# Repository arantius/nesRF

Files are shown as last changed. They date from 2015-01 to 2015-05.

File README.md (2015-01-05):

nesRF is a project to retrofit wireless capability into otherwise standard
NES and SNES video game controllers.  It is both hardware (schematic and PCB)
and software (running on an ATMega microcontroller).

The primary goals are:

* Clean design.  External appearance should be minimal, with few visible
  changes from the original stock hardware, besides removing the wire.
* Cross-compatibility: especially, the SNES controller will co-operate with
  either the SNES or NES receiver.

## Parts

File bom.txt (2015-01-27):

TX:

All 0402 capacitors and resistors:

C 0.1u * 4
C 4.7u * 2
C 1u

R 10k * 4
R 19.1k
R 180
R 300k
R 100k

One each:

MCU: ATMEGA328A TQPF-32
Voltage regulator: TCR2EF25,LM(CT SOT-23-5
Li-ion charger: MCP73832T-2ACI/OT SOT-23-5
Voltage detector: BD49K30G-TL SSOP-3
TVS: VC060305A150DP 0603
ISP Header: M20-9980345
Illuminated pushbutton: WBL2UEEGYQR05CLR

RX:

All 0402 capacitors and resistors:

C 0.1u * 4
C 1u

R 10k * 2
R 180

One each:

MCU: ATMEGA328A TQPF-32
Bi-color LED: WP59GYW
ISP Header: M20-9980345

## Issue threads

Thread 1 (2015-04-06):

SNES TX PCB Shape

arantius, 2015-04-06:
A couple issues with the shape of this PCB:

1. Major: there's no space for the pivot points of the shoulder buttons.  This can, barely, be dremeled out safely without affecting performance.
2. The cutout for the R shoulder button daughter board is almost perfect, but a very tight fit.  The L on the other hand is too loose in every dimension.  Somewhere in between the two would be best.

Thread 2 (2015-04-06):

SNES RX Should be interrupt driven

arantius, 2015-04-06:
I was too obsessed with parts count reduction.  I included no crystals anywhere, relying on the 8MHz RC circuit.  Early tests showed this to be sufficient.  To make this work, I had to go mostly software driven, as I couldn't reliably interrupt in 6ms based on the clock signal, when building the SNES RX.

Turns out I also can't reliably interrupt with the 18ms available completely 100% of the time from latch rise to first clock drop, either.  Occasionally as a result buttons get missed.  Now that I've done the NES RX, fully interrupt driven -- and at 16MHz because I expected it to be more difficult to handle both players -- I'm pretty confident that it would be better to fully interrupt drive the SNES RX as well.  But again, at 8MHz that doesn't seem possible.

arantius, 2015-05-25:
f2887791ccca9e47665a93060e8486ed92c85b78 c5f8425099a87a260d53bb1839957d2f6069903e

Closed 2015-05-25.

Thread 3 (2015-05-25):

NES transmitter range

arantius, 2015-05-25:
Unfortunately the RF board ended up sandwiched between the original PCB and my add-in daughterboard.  It seems that this has some consequences to the effective range, with the antenna surrounded by quite a lot of material.

I think redesigning so the RF board is at the absolute bottom of the stack should help, as (at least personally) the controller tends to be held around a 45 degree angle, with the bottom well exposed towards the console.  This may have the side benefit of locating the power jack closer to the original hole for the wire, but would probably involve a complete redesign of the board.

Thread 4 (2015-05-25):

NES transmitter shape

arantius, 2015-05-25:
The cutout around the screw support isn't lined up well, a shaving a bit of that support off is necessary.

The switch is not located well, shaving off a bit of the inside of the case is necessary to make it fit.  It should come in by up to ~1mm.

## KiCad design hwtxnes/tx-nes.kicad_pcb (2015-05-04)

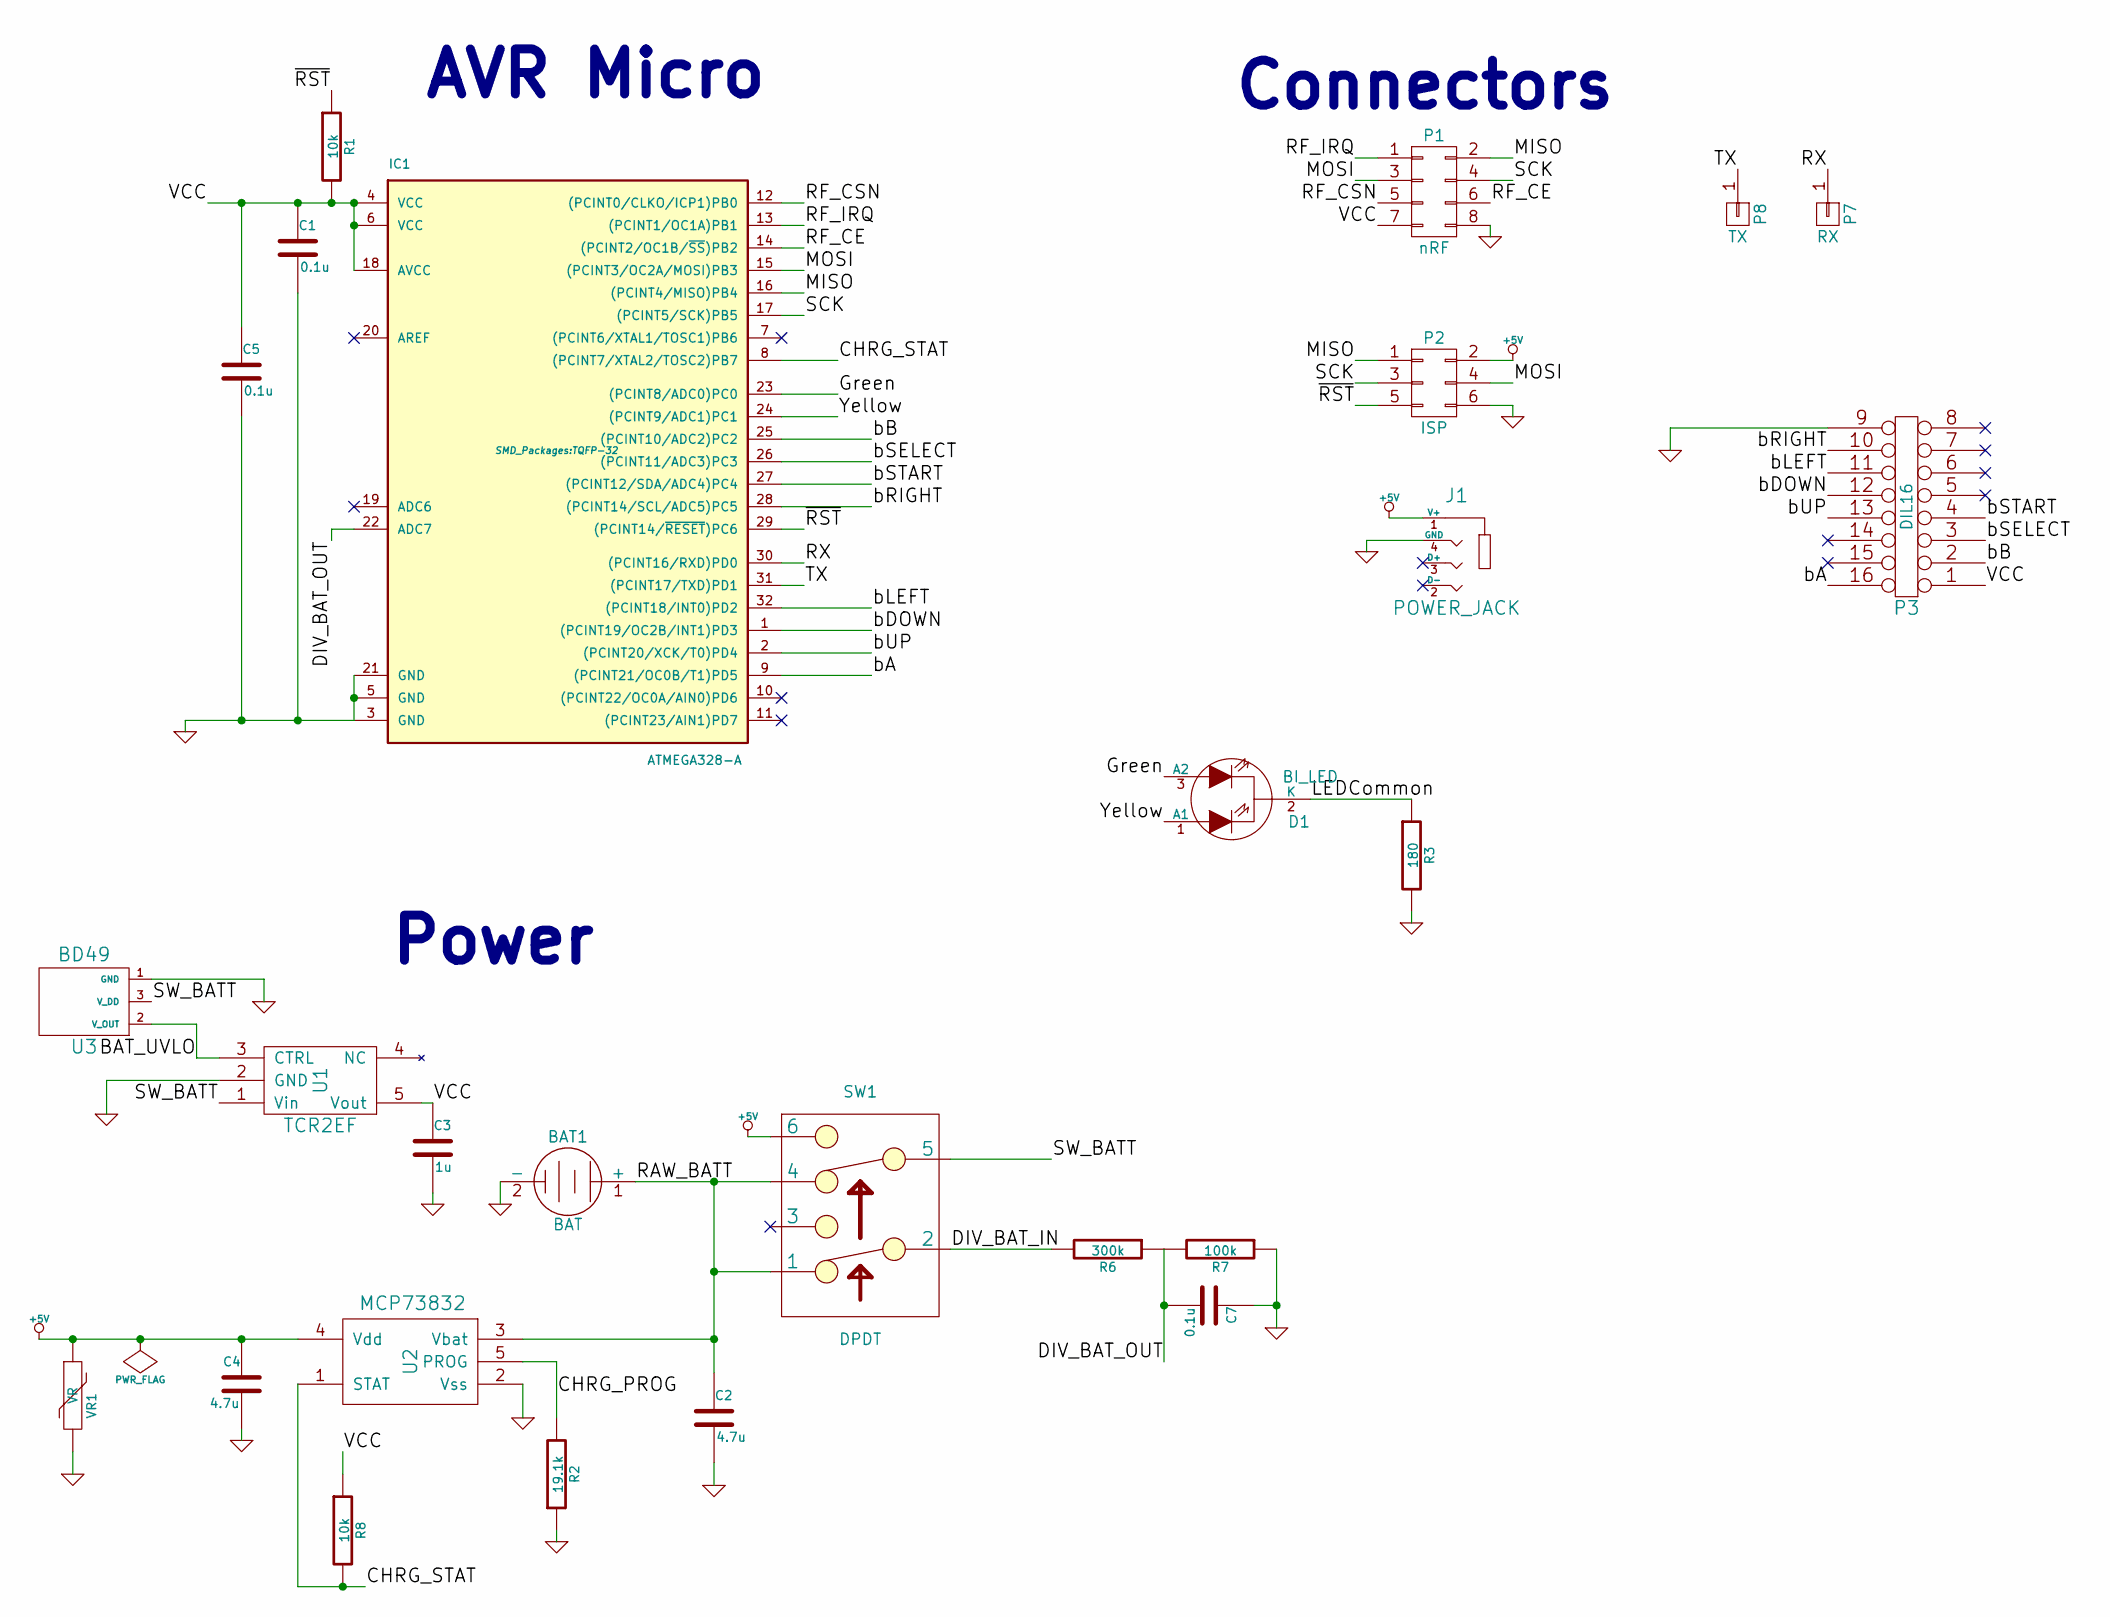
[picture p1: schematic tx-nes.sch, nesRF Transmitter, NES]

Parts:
BAT1: BAT; PINHEAD1-2
C1, C5, C7: 0.1u; C_0402
C2, C4: 4.7u; C_0402
C3: 1u; C_0402
D1: BI_LED; Pin_Header_Straight_1x03
IC1: ATMEGA328-A; TQFP-32
J1: POWER_JACK; SJ-4351x
P1: nRF; nRF_Header_2x04
P2: ISP; ISP_POGO
P3: DIL16; NES_PCB_INTERCONNECT
P7: RX; SolderWirePad_single_0-8mmDrill
P8: TX; SolderWirePad_single_0-8mmDrill
R1, R8: 10k; R_0402
R2: 19.1k; R_0402
R3: 180; R_0402
R6: 300k; R_0402
R7: 100k; R_0402
SW1: DPDT; SK22D01
U1: TCR2EF; SOT23-5
U2: MCP73832; SOT23-5
U3: BD49; SSOP-3
VR1: VR; SMD-0603

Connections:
+5V: C4.1, J1.1 (V+), P2.2, SW1.6, U2.4 (Vdd), VR1.1
/BAT_UVLO: U1.3 (CTRL), U3.2 (V_OUT)
/CHRG_PROG: R2.2, U2.5 (PROG)
/CHRG_STAT: IC1.8 ((PCINT7/XTAL2/TOSC2)PB7), R8.2, U2.1 (STAT)
/DIV_BAT_IN: R6.2, SW1.2
/DIV_BAT_OUT: C7.2, IC1.22 (ADC7), R6.1, R7.2
/Green: D1.3 (A2), IC1.23 ((PCINT8/ADC0)PC0)
/LEDCommon: D1.2 (K), R3.1
/MISO: IC1.16 ((PCINT4/MISO)PB4), P1.2, P2.1
/MOSI: IC1.15 ((PCINT3/OC2A/MOSI)PB3), P1.3, P2.4
/RAW_BATT: BAT1.1 (+), C2.1, SW1.1, SW1.4, U2.3 (Vbat)
/RF_CE: IC1.14 ((PCINT2/OC1B/~SS~)PB2), P1.6
/RF_CSN: IC1.12 ((PCINT0/CLKO/ICP1)PB0), P1.5
/RF_IRQ: IC1.13 ((PCINT1/OC1A)PB1), P1.1
/RX: IC1.30 ((PCINT16/RXD)PD0), P7.1
/SCK: IC1.17 ((PCINT5/SCK)PB5), P1.4, P2.3
/SW_BATT: SW1.5, U1.1 (Vin), U3.3 (V_DD)
/TX: IC1.31 ((PCINT17/TXD)PD1), P8.1
/VCC: C1.1, C3.1, C5.1, IC1.4 (VCC), IC1.6 (VCC), IC1.18 (AVCC), P1.7, P3.1, R1.2, R8.1, U1.5 (Vout)
/Yellow: D1.1 (A1), IC1.24 ((PCINT9/ADC1)PC1)
/bA: IC1.9 ((PCINT21/OC0B/T1)PD5), P3.16
/bB: IC1.25 ((PCINT10/ADC2)PC2), P3.2
/bDOWN: IC1.1 ((PCINT19/OC2B/INT1)PD3), P3.12
/bLEFT: IC1.32 ((PCINT18/INT0)PD2), P3.11
/bRIGHT: IC1.28 ((PCINT14/SCL/ADC5)PC5), P3.10
/bSELECT: IC1.26 ((PCINT11/ADC3)PC3), P3.3
/bSTART: IC1.27 ((PCINT12/SDA/ADC4)PC4), P3.4
/bUP: IC1.2 ((PCINT20/XCK/T0)PD4), P3.13
/~RST: IC1.29 ((PCINT14/~RESET~)PC6), P2.5, R1.1
GND: BAT1.2 (-), C1.2, C2.2, C3.2, C4.2, C5.2, C7.1, IC1.3 (GND), IC1.5 (GND), IC1.21 (GND), J1.4 (GND), P1.8, P2.6, P3.9, R2.1, R3.2, R7.1, U1.2 (GND), U2.2 (Vss), U3.1 (GND), VR1.2

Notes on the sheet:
Connectors
AVR Micro
Power

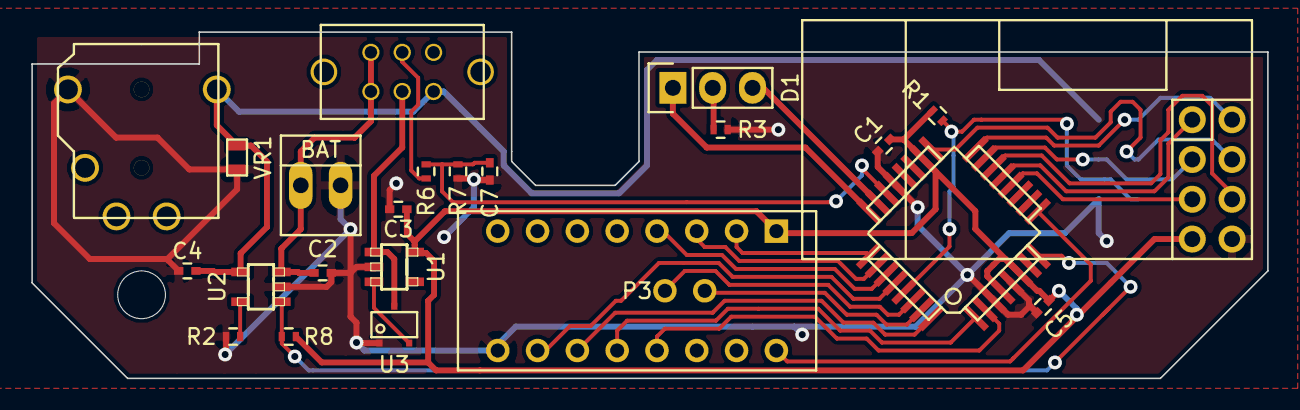
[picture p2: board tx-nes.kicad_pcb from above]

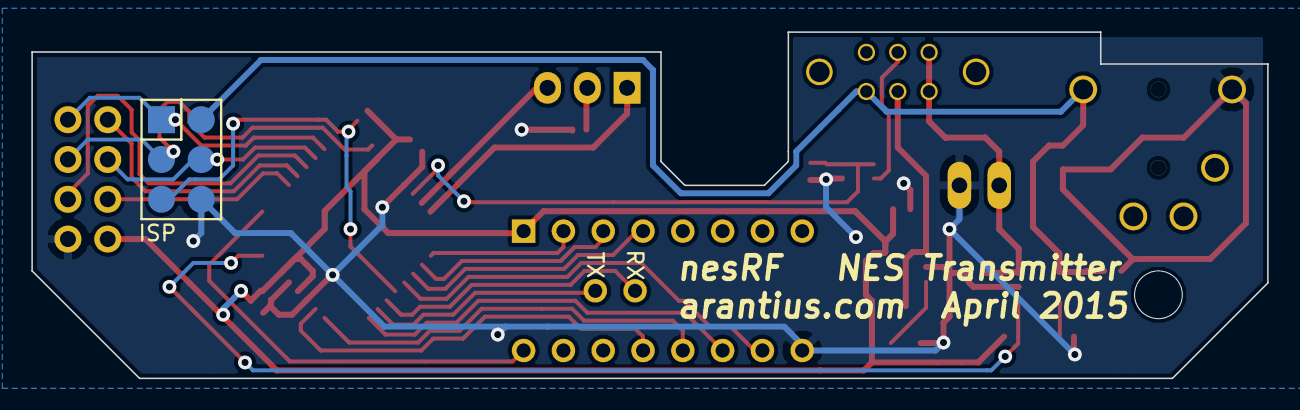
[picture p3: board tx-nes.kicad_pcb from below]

Board: 2 copper layers, 78.9 x 22.1 mm, 27 parts (3 on the bottom side), 30 nets.

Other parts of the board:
Mount_Hole: 1pin; NPTH_90

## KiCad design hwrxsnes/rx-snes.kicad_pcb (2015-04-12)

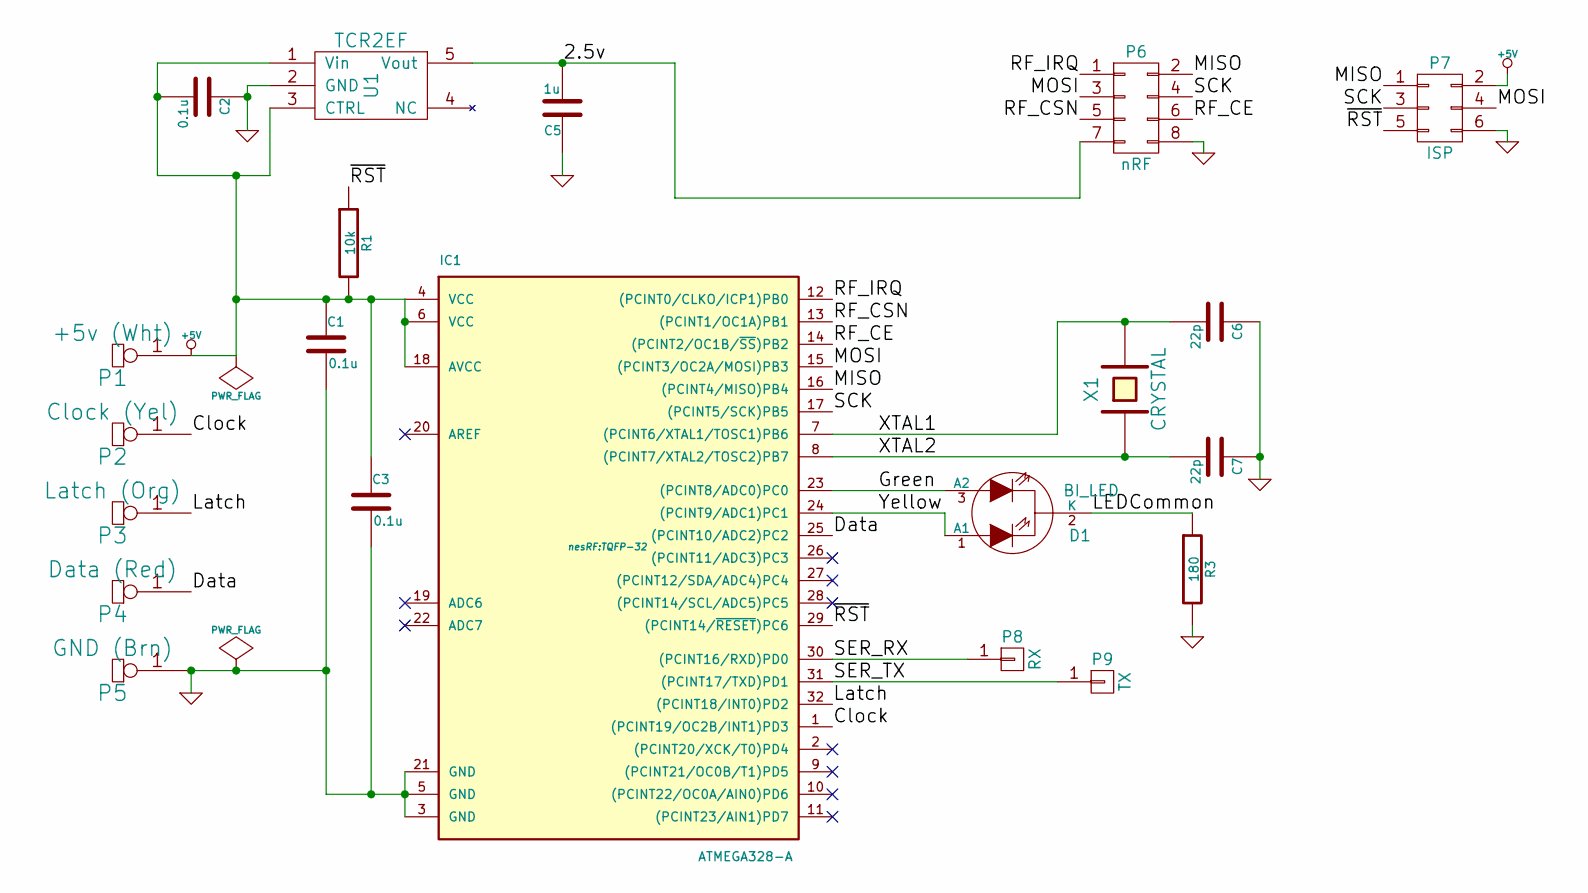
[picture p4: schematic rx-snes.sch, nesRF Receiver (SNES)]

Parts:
C1, C2, C3: 0.1u; C_0402
C5: 1u; C_0402
C6, C7: 22p; C_0402
D1: BI_LED; Pin_Header_Straight_1x03
IC1: ATMEGA328-A; TQFP-32
P1: +5v (Wht); Small_1x_Pad
P2: Clock (Yel); Small_1x_Pad
P3: Latch (Org); Small_1x_Pad
P4: Data (Red); Small_1x_Pad
P5: GND (Brn); Small_1x_Pad
P6: nRF; Pin_Header_Straight_2x04
P7: ISP; ISP_POGO
P8: RX; Small_1x_Pad
P9: TX; Small_1x_Pad
R1: 10k; R_0402
R3: 180; R_0402
U1: TCR2EF; SOT23-5
X1: CRYSTAL; TSX-3225

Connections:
+5V: C1.1, C2.2, C3.1, IC1.4 (VCC), IC1.6 (VCC), IC1.18 (AVCC), P1.1, P7.2, R1.2, U1.1 (Vin), U1.3 (CTRL)
/2.5v: C5.2, P6.7, U1.5 (Vout)
/Clock: IC1.1 ((PCINT19/OC2B/INT1)PD3), P2.1
/Data: IC1.25 ((PCINT10/ADC2)PC2), P4.1
/Green: D1.3 (A2), IC1.23 ((PCINT8/ADC0)PC0)
/LEDCommon: D1.2 (K), R3.1
/Latch: IC1.32 ((PCINT18/INT0)PD2), P3.1
/MISO: IC1.16 ((PCINT4/MISO)PB4), P6.2, P7.1
/MOSI: IC1.15 ((PCINT3/OC2A/MOSI)PB3), P6.3, P7.4
/RF_CE: IC1.14 ((PCINT2/OC1B/~SS~)PB2), P6.6
/RF_CSN: IC1.13 ((PCINT1/OC1A)PB1), P6.5
/RF_IRQ: IC1.12 ((PCINT0/CLKO/ICP1)PB0), P6.1
/SCK: IC1.17 ((PCINT5/SCK)PB5), P6.4, P7.3
/SER_RX: IC1.30 ((PCINT16/RXD)PD0), P8.1
/SER_TX: IC1.31 ((PCINT17/TXD)PD1), P9.1
/XTAL1: C6.2, IC1.7 ((PCINT6/XTAL1/TOSC1)PB6), X1.2
/XTAL2: C7.2, IC1.8 ((PCINT7/XTAL2/TOSC2)PB7), X1.1
/Yellow: D1.1 (A1), IC1.24 ((PCINT9/ADC1)PC1)
/~RST: IC1.29 ((PCINT14/~RESET~)PC6), P7.5, R1.1
GND: C1.2, C2.1, C3.2, C5.1, C6.1, C7.1, IC1.3 (GND), IC1.5 (GND), IC1.21 (GND), P5.1, P6.8, P7.6, R3.2, U1.2 (GND)

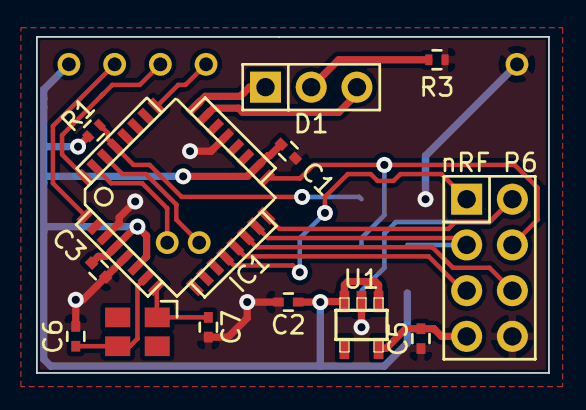
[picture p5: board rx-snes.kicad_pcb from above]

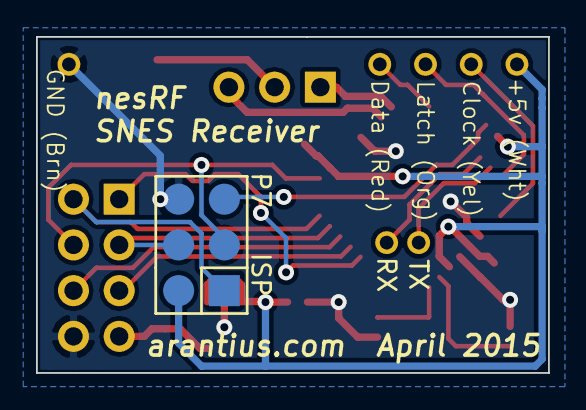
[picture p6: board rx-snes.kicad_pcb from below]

Board: 2 copper layers, 28.4 x 18.7 mm, 21 parts (3 on the bottom side), 20 nets.

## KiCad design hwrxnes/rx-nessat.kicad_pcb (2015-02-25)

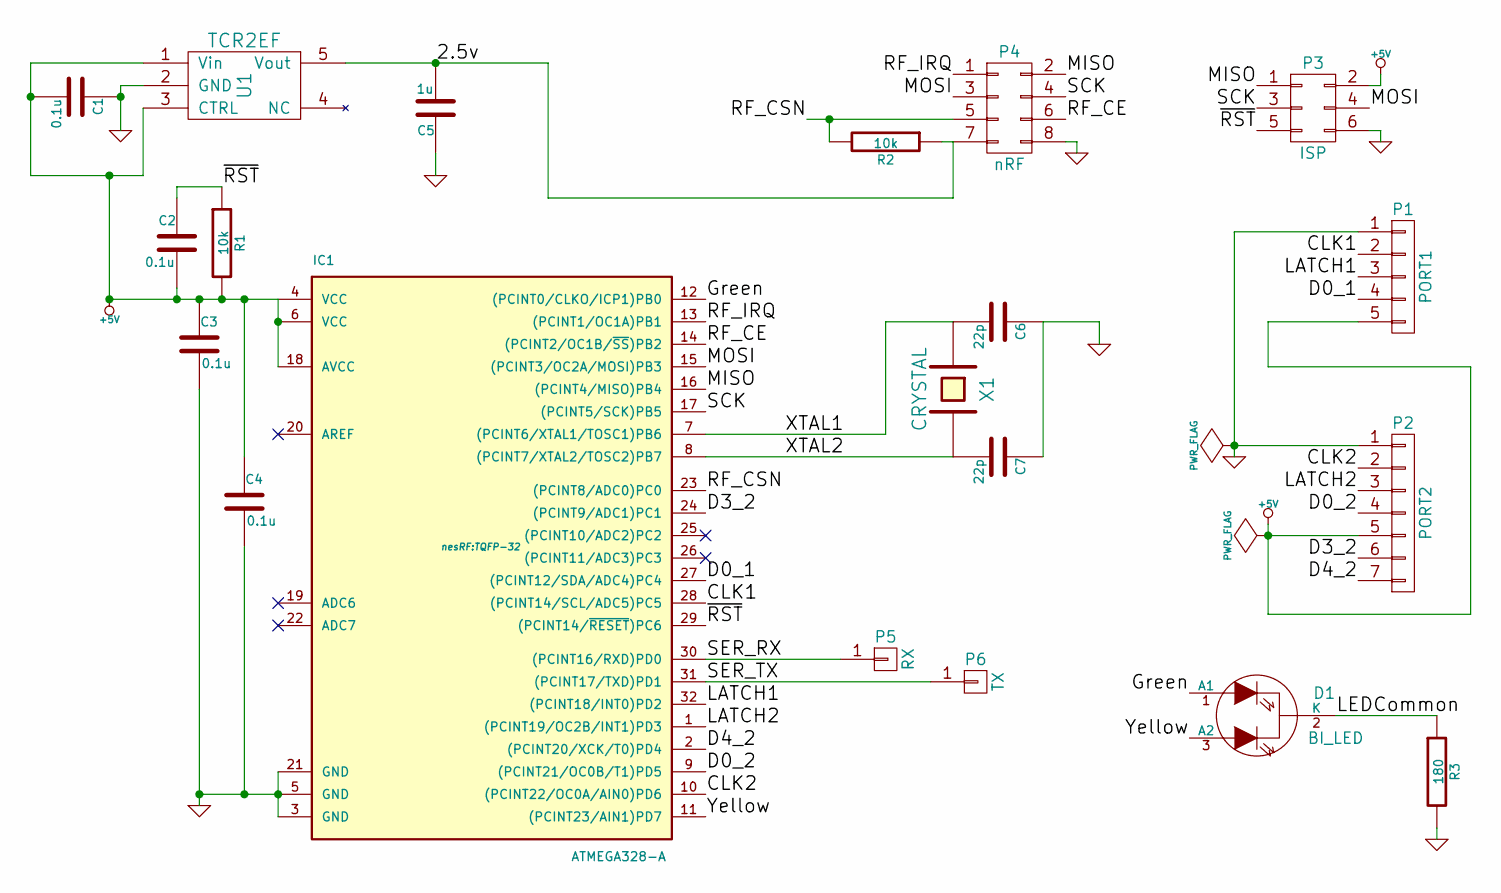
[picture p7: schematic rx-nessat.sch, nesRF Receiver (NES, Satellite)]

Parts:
C1, C2, C3, C4: 0.1u; C_0402
C5: 1u; C_0402
C6, C7: 22p; C_0402
D1: BI_LED; Pin_Header_Straight_1x03
IC1: ATMEGA328-A; TQFP-32
P1: PORT1; Pin_Header_Straight_1x05
P2: PORT2; Pin_Header_Straight_1x07
P3: ISP; Pin_Header_Straight_2x03
P4: nRF; nRF_Header_2x04
P5: RX; Small_1x_Pad
P6: TX; Small_1x_Pad
R1, R2: 10k; R_0402
R3: 180; R_0402
U1: TCR2EF; SOT23-5
X1: CRYSTAL; TSX-3225

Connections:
+5V: C1.2, C2.2, C3.1, C4.1, IC1.4 (VCC), IC1.6 (VCC), IC1.18 (AVCC), P1.5, P2.5, P3.2, R1.2, U1.1 (Vin), U1.3 (CTRL)
/2.5v: C5.2, P4.7, R2.1, U1.5 (Vout)
/CLK1: IC1.28 ((PCINT14/SCL/ADC5)PC5), P1.2
/CLK2: IC1.10 ((PCINT22/OC0A/AIN0)PD6), P2.2
/D0_1: IC1.27 ((PCINT12/SDA/ADC4)PC4), P1.4
/D0_2: IC1.9 ((PCINT21/OC0B/T1)PD5), P2.4
/D3_2: IC1.24 ((PCINT9/ADC1)PC1), P2.6
/D4_2: IC1.2 ((PCINT20/XCK/T0)PD4), P2.7
/Green: D1.1 (A1), IC1.12 ((PCINT0/CLKO/ICP1)PB0)
/LATCH1: IC1.32 ((PCINT18/INT0)PD2), P1.3
/LATCH2: IC1.1 ((PCINT19/OC2B/INT1)PD3), P2.3
/LEDCommon: D1.2 (K), R3.1
/MISO: IC1.16 ((PCINT4/MISO)PB4), P3.1, P4.2
/MOSI: IC1.15 ((PCINT3/OC2A/MOSI)PB3), P3.4, P4.3
/RF_CE: IC1.14 ((PCINT2/OC1B/~SS~)PB2), P4.6
/RF_CSN: IC1.23 ((PCINT8/ADC0)PC0), P4.5, R2.2
/RF_IRQ: IC1.13 ((PCINT1/OC1A)PB1), P4.1
/SCK: IC1.17 ((PCINT5/SCK)PB5), P3.3, P4.4
/SER_RX: IC1.30 ((PCINT16/RXD)PD0), P5.1
/SER_TX: IC1.31 ((PCINT17/TXD)PD1), P6.1
/XTAL1: C6.2, IC1.7 ((PCINT6/XTAL1/TOSC1)PB6), X1.1
/XTAL2: C7.2, IC1.8 ((PCINT7/XTAL2/TOSC2)PB7), X1.2
/Yellow: D1.3 (A2), IC1.11 ((PCINT23/AIN1)PD7)
/~RST: C2.1, IC1.29 ((PCINT14/~RESET~)PC6), P3.5, R1.1
GND: C1.1, C3.2, C4.2, C5.1, C6.1, C7.1, IC1.3 (GND), IC1.5 (GND), IC1.21 (GND), P1.1, P2.1, P3.6, P4.8, R3.2, U1.2 (GND)

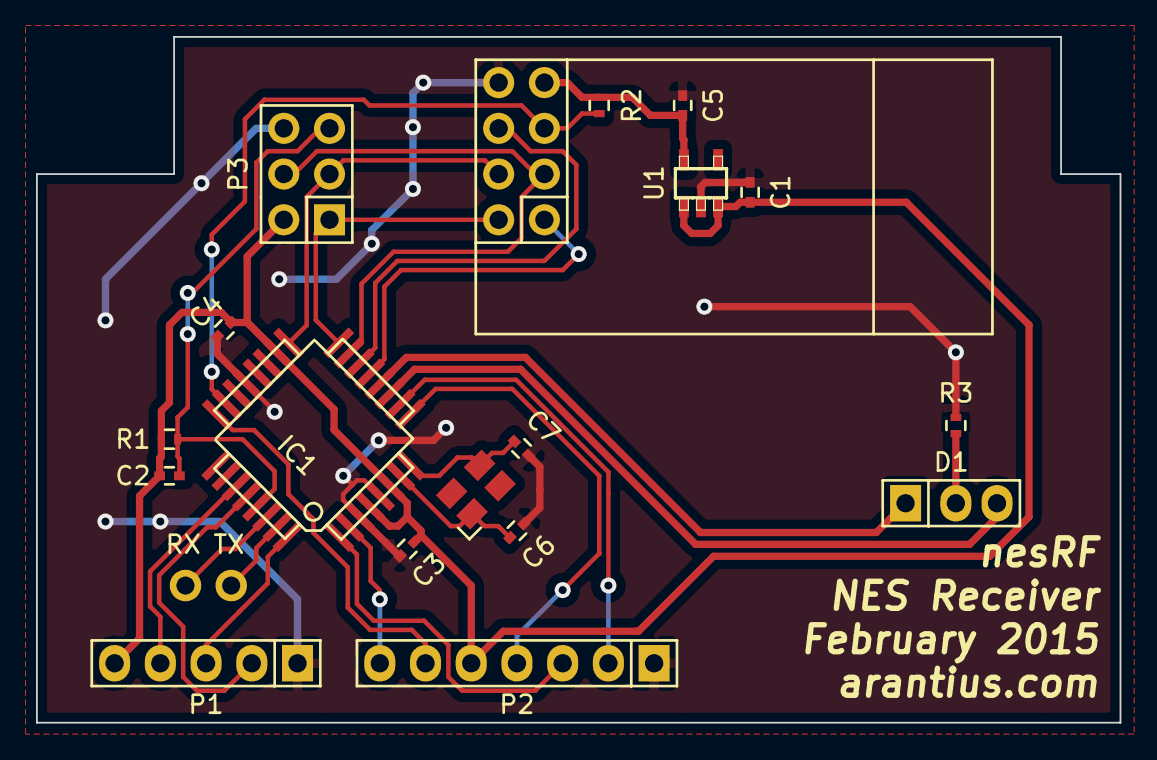
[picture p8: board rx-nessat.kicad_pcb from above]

Board: 2 copper layers, 60.2 x 38.1 mm, 20 parts (0 on the bottom side), 25 nets.

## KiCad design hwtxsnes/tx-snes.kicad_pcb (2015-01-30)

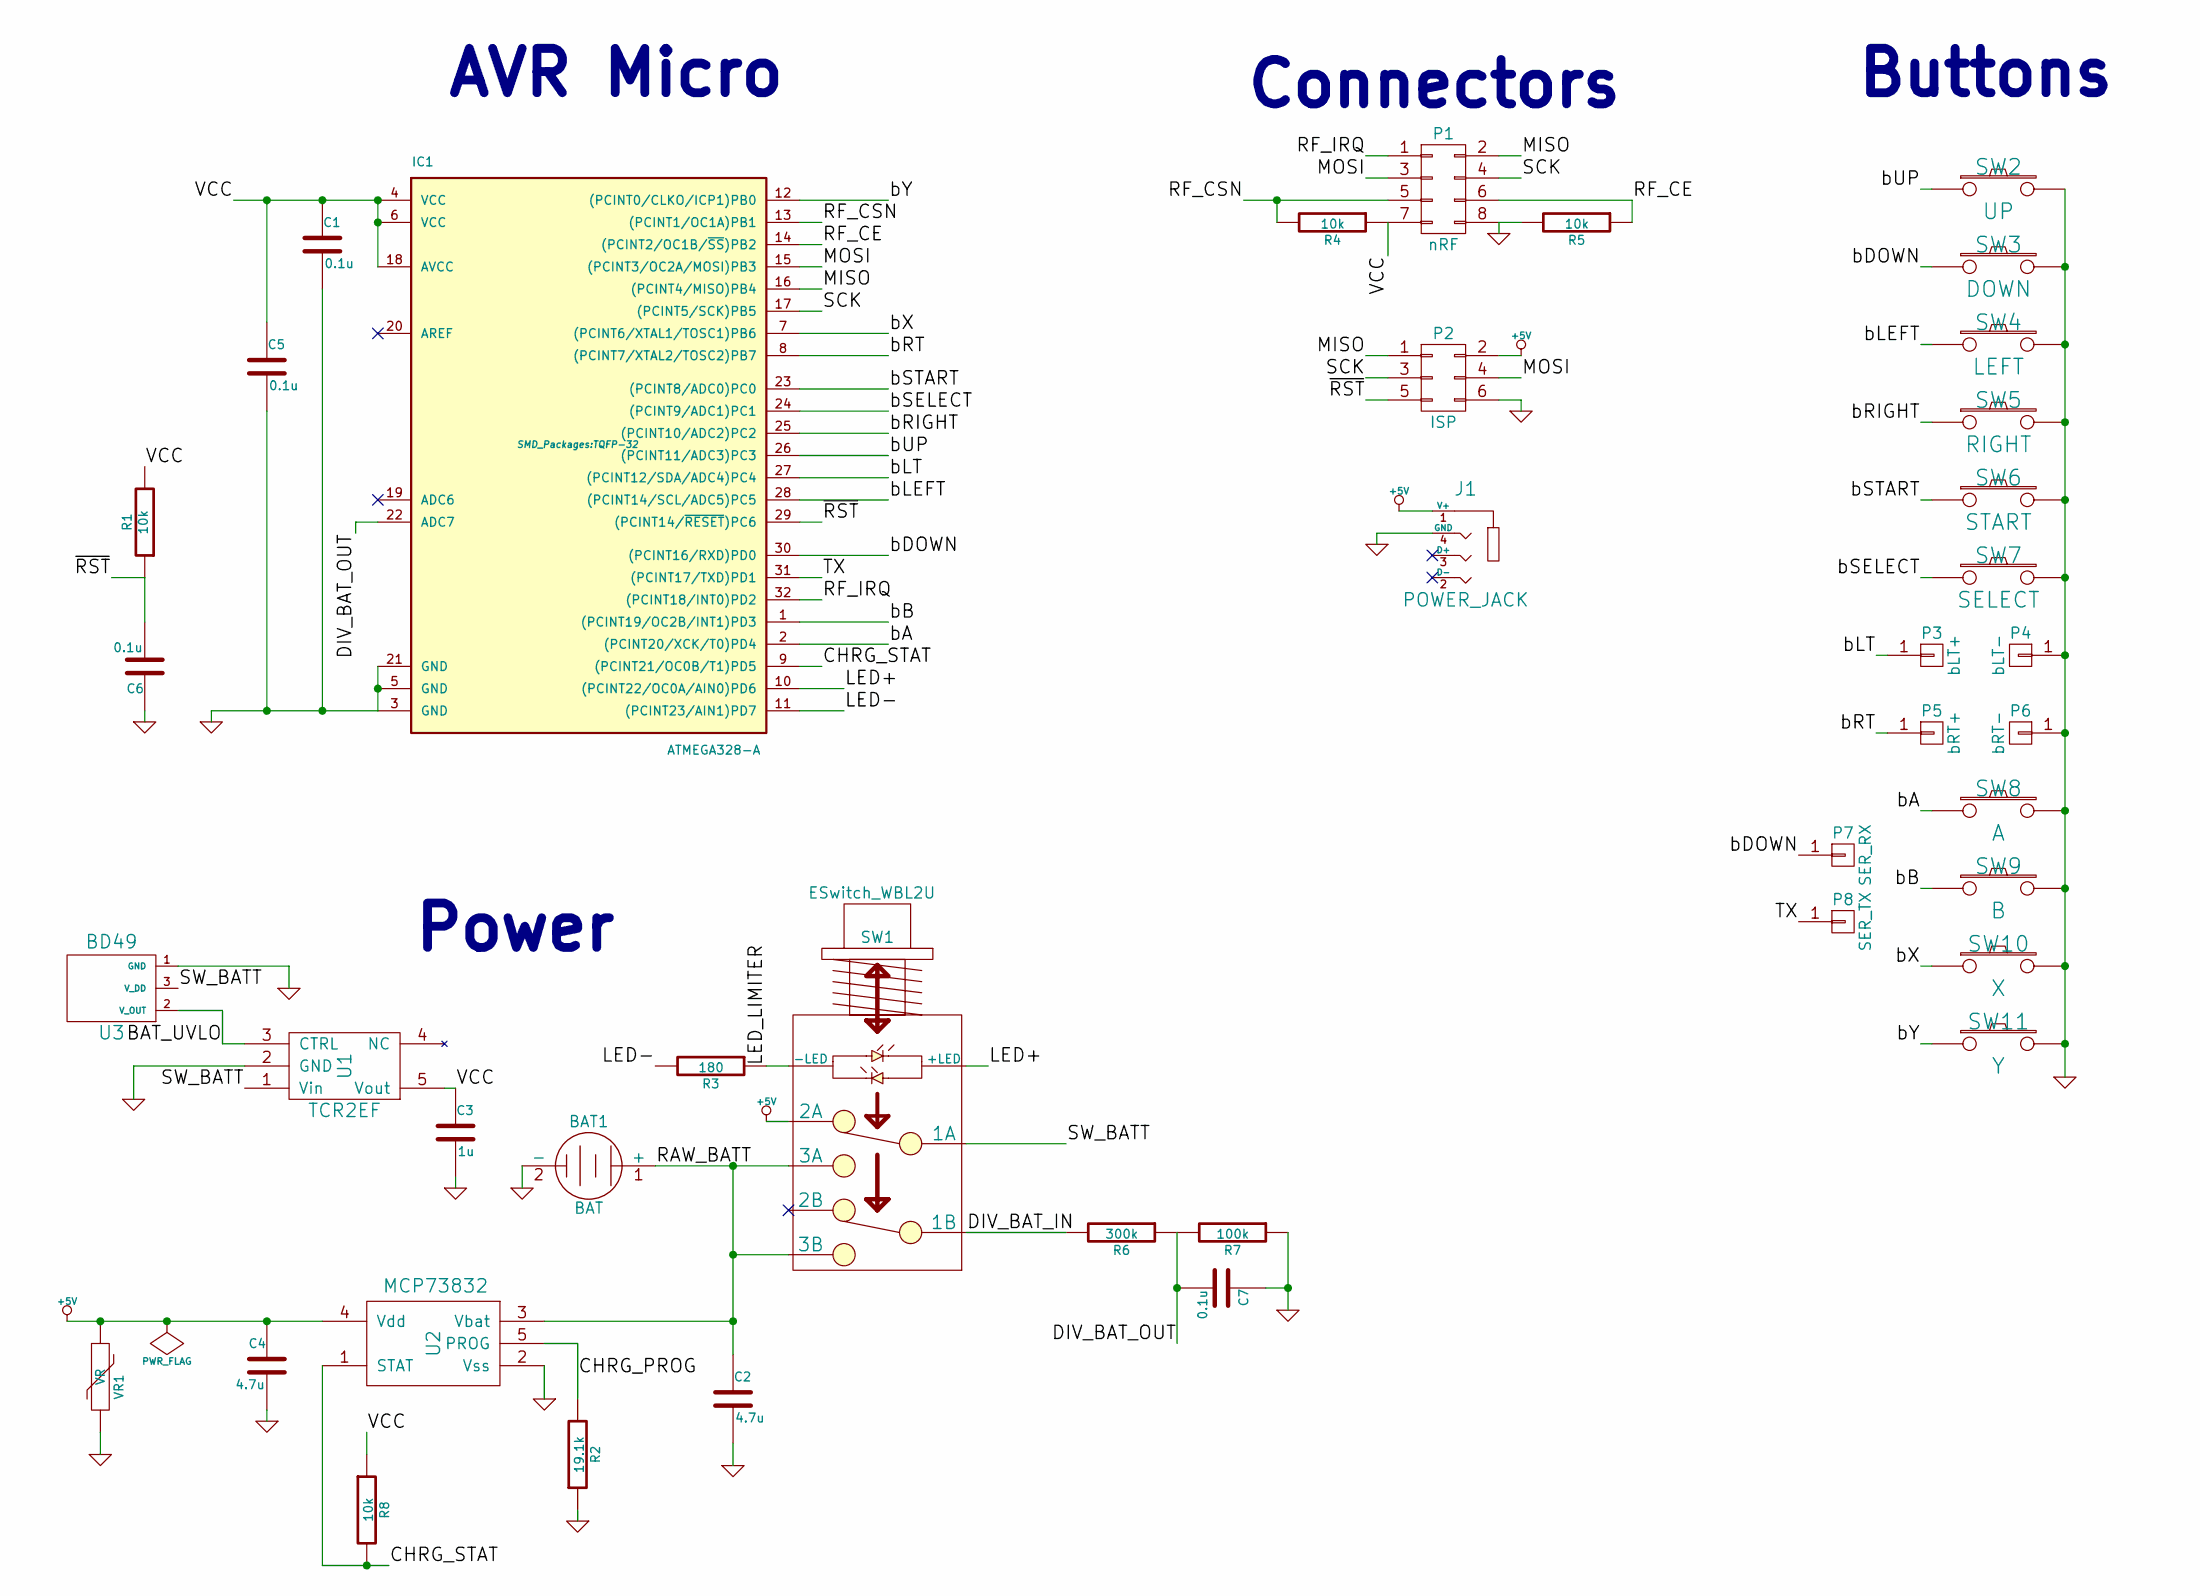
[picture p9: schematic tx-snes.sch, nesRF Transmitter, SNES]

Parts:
BAT1: BAT; PINHEAD1-2
C1, C5, C6, C7: 0.1u; SMD-0402_c
C2, C4: 4.7u; SMD-0402_c
C3: 1u; SMD-0402_c
IC1: ATMEGA328-A; TQFP-32
J1: POWER_JACK; SJ-4351x
P1: nRF; nRF_Header_2x04
P2: ISP; Pin_Header_Straight_2x03
P3: bLT+; SolderWirePad_single_0-8mmDrill
P4: bLT-; SolderWirePad_single_0-8mmDrill
P5: bRT+; SolderWirePad_single_0-8mmDrill
P6: bRT-; SolderWirePad_single_0-8mmDrill
P7: SER_RX; SolderWirePad_single_0-8mmDrill
P8: SER_TX; SolderWirePad_single_0-8mmDrill
R1, R4, R5, R8: 10k; SMD-0402_r
R2: 19.1k; SMD-0402_r
R3: 180; SMD-0402_r
R6: 300k; SMD-0402_r
R7: 100k; SMD-0402_r
SW1: ESwitch_WBL2U; Eswitch_WBL_2U
SW2: UP; Carbon_Switch_PCB_Pad
SW3: DOWN; Carbon_Switch_PCB_Pad
SW4: LEFT; Carbon_Switch_PCB_Pad
SW5: RIGHT; Carbon_Switch_PCB_Pad
SW6: START; Carbon_Switch_PCB_Pad
SW7: SELECT; Carbon_Switch_PCB_Pad
SW8: A; Carbon_Switch_PCB_Pad
SW9: B; Carbon_Switch_PCB_Pad
SW10: X; Carbon_Switch_PCB_Pad
SW11: Y; Carbon_Switch_PCB_Pad
U1: TCR2EF; SOT-23-5
U2: MCP73832; SOT-23-5
U3: BD49; SSOP-3
VR1: VR; SMD-0603

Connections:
+5V: C4.1, J1.1 (V+), P2.2, SW1.1 (2A), U2.4 (Vdd), VR1.1
/BAT_UVLO: U1.3 (CTRL), U3.2 (V_OUT)
/CHRG_PROG: R2.2, U2.5 (PROG)
/CHRG_STAT: IC1.9 ((PCINT21/OC0B/T1)PD5), R8.2, U2.1 (STAT)
/DIV_BAT_IN: R6.2, SW1.5 (1B)
/DIV_BAT_OUT: C7.2, IC1.22 (ADC7), R6.1, R7.2
/LED+: IC1.10 ((PCINT22/OC0A/AIN0)PD6), SW1.+ (+LED)
/LED-: IC1.11 ((PCINT23/AIN1)PD7), R3.2
/LED_LIMITER: R3.1, SW1.- (-LED)
/MISO: IC1.16 ((PCINT4/MISO)PB4), P1.2, P2.1
/MOSI: IC1.15 ((PCINT3/OC2A/MOSI)PB3), P1.3, P2.4
/RAW_BATT: BAT1.1 (+), C2.1, SW1.3 (3A), SW1.6 (3B), U2.3 (Vbat)
/RF_CE: IC1.14 ((PCINT2/OC1B/~SS~)PB2), P1.6, R5.1
/RF_CSN: IC1.13 ((PCINT1/OC1A)PB1), P1.5, R4.2
/RF_IRQ: IC1.32 ((PCINT18/INT0)PD2), P1.1
/SCK: IC1.17 ((PCINT5/SCK)PB5), P1.4, P2.3
/SW_BATT: SW1.2 (1A), U1.1 (Vin), U3.3 (V_DD)
/TX: IC1.31 ((PCINT17/TXD)PD1), P8.1
/VCC: C1.1, C3.1, C5.1, IC1.4 (VCC), IC1.6 (VCC), IC1.18 (AVCC), P1.7, R1.2, R4.1, R8.1, U1.5 (Vout)
/bA: IC1.2 ((PCINT20/XCK/T0)PD4), SW8.1
/bB: IC1.1 ((PCINT19/OC2B/INT1)PD3), SW9.1
/bDOWN: IC1.30 ((PCINT16/RXD)PD0), P7.1, SW3.1
/bLEFT: IC1.28 ((PCINT14/SCL/ADC5)PC5), SW4.1
/bLT: IC1.27 ((PCINT12/SDA/ADC4)PC4), P3.1
/bRIGHT: IC1.25 ((PCINT10/ADC2)PC2), SW5.1
/bRT: IC1.8 ((PCINT7/XTAL2/TOSC2)PB7), P5.1
/bSELECT: IC1.24 ((PCINT9/ADC1)PC1), SW7.1
/bSTART: IC1.23 ((PCINT8/ADC0)PC0), SW6.1
/bUP: IC1.26 ((PCINT11/ADC3)PC3), SW2.1
/bX: IC1.7 ((PCINT6/XTAL1/TOSC1)PB6), SW10.1
/bY: IC1.12 ((PCINT0/CLKO/ICP1)PB0), SW11.1
/~RST: C6.2, IC1.29 ((PCINT14/~RESET~)PC6), P2.5, R1.1
GND: BAT1.2 (-), C1.2, C2.2, C3.2, C4.2, C5.2, C6.1, C7.1, IC1.3 (GND), IC1.5 (GND), IC1.21 (GND), J1.4 (GND), P1.8, P2.6, P4.1, P6.1, R2.1, R5.2, R7.1, SW2.2, SW3.2, SW4.2, SW5.2, SW6.2, SW7.2, SW8.2, SW9.2, SW10.2, SW11.2, U1.2 (GND), U2.2 (Vss), U3.1 (GND), VR1.2

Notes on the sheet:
Buttons
Connectors
AVR Micro
Power

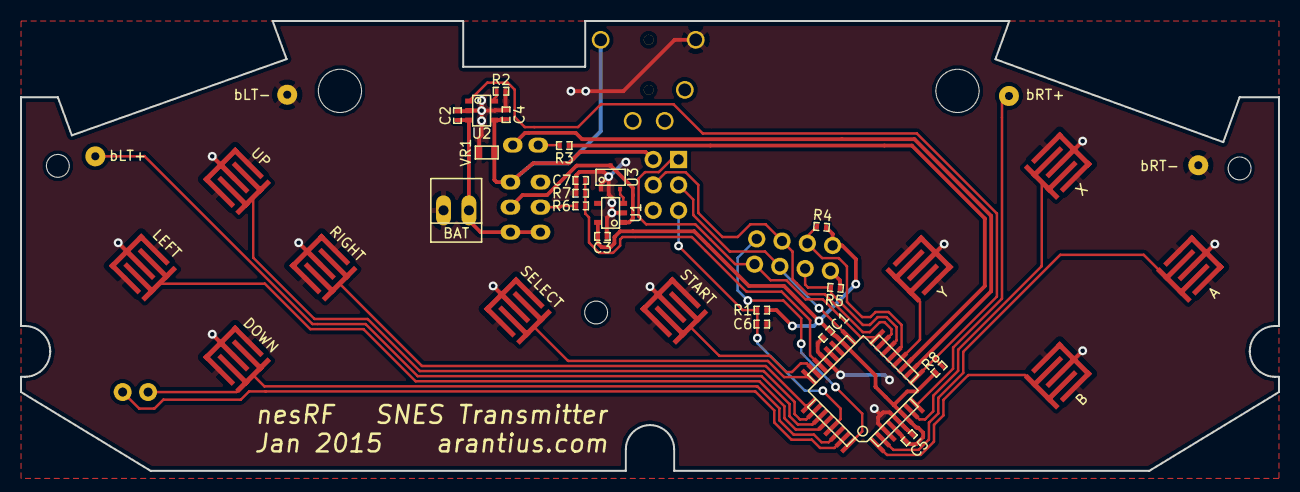
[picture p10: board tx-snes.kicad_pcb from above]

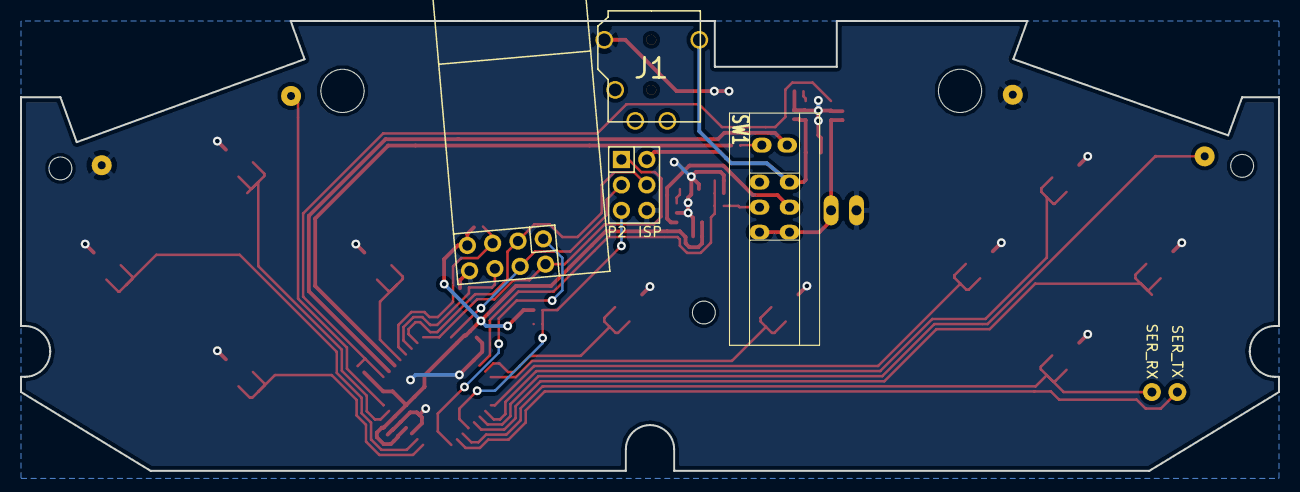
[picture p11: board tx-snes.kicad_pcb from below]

Board: 2 copper layers, 125.7 x 45.0 mm, 46 parts (6 on the bottom side), 33 nets.

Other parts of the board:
MH1, MH3, MH5: MHole; MOUNT_HOLE_80
MH2, MH4: MHole; MOUNT_HOLE_170

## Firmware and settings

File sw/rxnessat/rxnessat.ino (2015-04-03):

/*
nesRF Wireless Controller Retrofit: Receiver
Copyright 2014 Anthony Lieuallen

This code is responsible for what needs to happen in the receiver:
1) Read the state of all the buttons, via RF.
2) Transmit that to the console.
*/

// Define this to send debugging data out via Serial.
//#define DEBUG

// Addresses of data stored in EEPROM.
#define EEPROM_RF_CHAN 0x00 /* One byte, the RF channel. */
#define EEPROM_RF_ADDR 0x01 /* Five bytes, the RF address. */

#define BLINK_INTERVAL 333
#define DATA_MIN_INTERVAL 2048

// \\ // \\ // \\ // \\ // \\ // \\ // \\ // \\ // \\ // \\ // \\ // \\ // \\ //

#include <EEPROM.h>
#include <SPI.h>

#include "nRF24L01.h"
#include "RF24.h"
#ifdef DEBUG
#include "printf.h"
#endif

// \\ // \\ // \\ // \\ // \\ // \\ // \\ // \\ // \\ // \\ // \\ // \\ // \\ //

#define PORT_LATCH1 PORTD
#define PIN_LATCH1 _BV(2)

#define PORT_LATCH2 PORTD
#define PIN_LATCH2 _BV(3)

#define PORT_CLK1 PORTC
#define PIN_CLK1 _BV(5)

#define PORT_CLK2 PORTD
#define PIN_CLK2 _BV(6)

#define PORT_D0P1 PORTC
#define PIN_D0P1 _BV(4)

#define PORT_D0P2 PORTD
#define PIN_D0P2 _BV(5)

#define PORT_D3P2 PORTC
#define PIN_D3P2 _BV(1)

#define PORT_D4P2 PORTD
#define PIN_D4P2 _BV(4)

#define PORT_GRN PORTB
#define PIN_GRN _BV(0)

#define PORT_YEL PORTD
#define PIN_YEL _BV(7)

// \\ // \\ // \\ // \\ // \\ // \\ // \\ // \\ // \\ // \\ // \\ // \\ // \\ //

RF24 radio(10, 14);  // CE, CS pins
unsigned long gDataTimeMax = 0;
unsigned long gDataTime[2] = {0, 0};
uint16_t gNextTurbo = 0;
volatile uint8_t gData[2] = {0xFF, 0xFF};
uint8_t gShiftBit[2] = {1, 1};
uint8_t gTurboActive = 0;
uint8_t gTurboMask[2] = {0xFF, 0xFF};

// \\ // \\ // \\ // \\ // \\ // \\ // \\ // \\ // \\ // \\ // \\ // \\ // \\ //

#define lightLedOff() PORT_GRN &= ~PIN_GRN; PORT_YEL &= ~PIN_YEL;
#define lightLedGrn() PORT_YEL &= ~PIN_YEL; PORT_GRN |= PIN_GRN;
#define lightLedYel() PORT_GRN &= ~PIN_GRN; PORT_YEL |= PIN_YEL;

// \\ // \\ // \\ // \\ // \\ // \\ // \\ // \\ // \\ // \\ // \\ // \\ // \\ //

// TODO: Handle players 3 through 4.
void ISR_latch() {
  // NES protocol is, for each read: one wide high-going LATCH pulse,
  // followed by eight narrow low-going CLK pulses.  While CLK is low,
  // the console is reading data.

  // Initialize the bit mask.
  gShiftBit[0] = 1;
  gShiftBit[1] = 1;
  // Set the initial data line values.
  ISR_clock1();
  ISR_clock2();
}

inline void ISR_clock1() {
  // If clock is low we caught a falling edge; cancel and wait for rising.
  if (!(PINC & PIN_CLK1)) return;

  if ( (gData[0] & gShiftBit[0]) == 0
      || (gTurboActive && ((gTurboMask[0] & gShiftBit[0]) == 0))
  ) {
    PORT_D0P1 &= ~PIN_D0P1;
  } else {
    PORT_D0P1 |= PIN_D0P1;
  }

  gShiftBit[0] <<= 1;

  // In case we caught the falling edge, but couldn't read clock until
  // it rose, clear the interrupt flag so we don't re-execute on rising.
  PCIFR |= _BV(PCIF1);
}

inline void ISR_clock2() {
  // If clock is low we caught a falling edge; cancel and wait for rising.
  if (!(PIND & PIN_CLK2)) return;

  if ( (gData[1] & gShiftBit[1]) == 0
      || (gTurboActive && ((gTurboMask[1] & gShiftBit[1]) == 0))
  ) {
    PORT_D0P2 &= ~PIN_D0P2;
  } else {
    PORT_D0P2 |= PIN_D0P2;
  }

  gShiftBit[1] <<= 1;

  // In case we caught the falling edge, but couldn't read clock until
  // it rose, clear the interrupt flag so we don't re-execute on rising.
  PCIFR |= _BV(PCIF2);
}

SIGNAL(PCINT1_vect) { ISR_clock1(); }
SIGNAL(PCINT2_vect) { ISR_clock2(); }

// \\ // \\ // \\ // \\ // \\ // \\ // \\ // \\ // \\ // \\ // \\ // \\ // \\ //

void loop(void) {
  unsigned long now = millis();

  // Light the LED as per the last time any data was received.
  if (gDataTimeMax && (gDataTimeMax + DATA_MIN_INTERVAL > now)) {
    lightLedGrn();
  } else {
    lightLedYel();
  }

  // Reset either player's data if it's been too long since last data.
  for (uint8_t i = 0; i < 2; i++) {
    if (gDataTime[i] && (gDataTime[i] + DATA_MIN_INTERVAL < now)) {
      gDataTime[i] = 0;
      gDataTimeMax = gDataTime[2 - i];
      gData[i] = 0xFF;
    }
  }

  // Flip turbo status on a ~30Hz period.
  if (now > gNextTurbo) {
    gNextTurbo = now + 33;
    gTurboActive = ~gTurboActive;
  }

  // TODO: Set appropriate masks and just read RF_IRQ pin to see pending data?
  uint16_t data_raw = 0;
  uint8_t pipe;
  while (radio.available()) {
    uint8_t status = radio.get_status();
    pipe = (status >> 1) & 0x07;
    #ifdef DEBUG
    printf("Reading from pipe number %d ... ", pipe);
    #endif
    if (pipe > 1) {
      #ifdef DEBUG
      printf("Panic!  Data on unsupported pipe!\n");
      #endif
      return;
    }
    radio.read(&data_raw, sizeof(data_raw));
  }

  if (data_raw) {
    // TODO: Read multiple controllers.
    // TODO: Use battery/sleeping status bits?

    // Translate RF data to NES data.
    uint8_t data_nes = 0x00;
    uint8_t turbo_mask = 0xFF;
    data_nes = data_nes << 1; if (data_raw & _BV(7)) data_nes |= 1; // Right
    data_nes = data_nes << 1; if (data_raw & _BV(6)) data_nes |= 1; // Left
    data_nes = data_nes << 1; if (data_raw & _BV(5)) data_nes |= 1; // Down
    data_nes = data_nes << 1; if (data_raw & _BV(4)) data_nes |= 1; // Up
    data_nes = data_nes << 1; if (data_raw & _BV(3)) data_nes |= 1; // Start
    data_nes = data_nes << 1; if (data_raw & _BV(2)) data_nes |= 1; // Select
    data_nes = data_nes << 1; if (data_raw & _BV(0)) data_nes |= 1; // B
    if (!(data_raw & _BV(1))) turbo_mask &= ~_BV(1); // Y = B Turbo
    data_nes = data_nes << 1; if (data_raw & _BV(8)) data_nes |= 1; // A
    if (!(data_raw & _BV(9))) turbo_mask &= ~_BV(0); // X = A Turbo

    #ifdef DEBUG
    printf("RX got %04x; Translt. %02x; Turbo %02x\n",
        data_raw, data_nes, turbo_mask);
    #endif

    // TODO: X/Y as turbo for A/B.

    gData[pipe] = data_nes;
    gDataTimeMax = now;
    gDataTime[pipe] = now;
    gTurboMask[pipe] = turbo_mask;
  }
}


void setup() {
  #ifdef DEBUG
  Serial.begin(57600);
  printf_begin();
  printf("\n\n\nnesRF RX begin\n");
  #endif

  radio.begin();
  radio.setAutoAck(1);
  radio.setCRCLength(RF24_CRC_16);
  radio.setChannel(EEPROM.read(EEPROM_RF_CHAN));
  radio.setDataRate(RF24_1MBPS);
  radio.setPALevel(RF24_PA_MAX);
  radio.setPayloadSize(sizeof(uint16_t));
  radio.setRetries(7, 10);  // delay, retries

  byte address[5] = {};
  for (int i = 0; i < 5; i++) {
    address[i] = EEPROM.read(EEPROM_RF_ADDR + i);
  }

  radio.stopListening();
  radio.openReadingPipe(0, address);
  address[0]++;
  radio.openReadingPipe(1, address);
  address[0]++;
  radio.openReadingPipe(2, address);
  address[0]++;
  radio.openReadingPipe(3, address);
  radio.startListening();

  // The LED indicator is hooked up to pins PB0 (Green) and PD7 (Yellow).
  DDRB |= PIN_GRN;
  DDRD |= PIN_YEL;
  // Pins D0_1, D0_2, D3_2, D4_2.
  DDRC |= PIN_D0P1 | PIN_D3P2;
  DDRD |= PIN_D0P2 | PIN_D4P2;

  // The CLOCK and LATCH signals should be pullup enabled inputs.
  DDRC &= ~PIN_CLK1;
  DDRD &= ~(PIN_LATCH1 | PIN_LATCH2 | PIN_CLK2);
  PORTD |= PIN_CLK1;
  PORTD |= PIN_LATCH1 | PIN_LATCH2 | PIN_CLK2;

  // LATCH1 interrupt.
  attachInterrupt(0, ISR_latch, RISING);
  // CLK change interrupts.
  PCICR = _BV(PCIE1) | _BV(PCIE2);
  PCMSK1 = _BV(PCINT13);  // CLK1
  PCMSK2 = _BV(PCINT22);  // CLK2

  #ifdef DEBUG
  printf("\n");
  radio.printDetails();
  printf("\n");
  #endif
}

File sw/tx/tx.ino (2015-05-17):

/*
nesRF Wireless Controller Retrofit
Transmitter

Copyright 2014 Anthony Lieuallen

This code is responsible for what needs to happen in the controller:
1) Read the state of all the buttons.
2) Transmit that to the receiver.
3) Monitor the battery level, so the user can be warned as it drops.
4) Indicate when there is an RF connection (OK) or problem (error).
*/

// Define this to send debugging data out via Serial.
//#define DEBUG

// Define one of CONS_NES or CONS_SNES to indicate which transmitter we are.
#define CONS_NES

// Addresses of data stored in EEPROM.
#define EEPROM_RF_CHAN 0x00 /* One byte, the RF channel. */
#define EEPROM_RF_ADDR 0x01 /* Five bytes, the RF address. */
#define EEPROM_BAT_LOW 0x06 /* Two bytes, low battery threshold. */

#define EVENT_PIN_CHANGE 1
#define EVENT_TIMER 2

// \\ // \\ // \\ // \\ // \\ // \\ // \\ // \\ // \\ // \\ // \\ // \\ // \\ //

#include <avr/sleep.h>
#include <avr/power.h>
#include <EEPROM.h>
#include <SPI.h>

#include "nRF24L01.h"
#include "RF24.h"
#ifdef DEBUG
#include "printf.h"
#endif

// \\ // \\ // \\ // \\ // \\ // \\ // \\ // \\ // \\ // \\ // \\ // \\ // \\ //

#if defined(CONS_NES)
  RF24 radio(10, 8);  // CE, CS pins
#elif defined(CONS_SNES)
  RF24 radio(10, 9);  // CE, CS pins
#endif

#if defined(CONS_NES)
#define DDR_LED DDRC
#define PORT_LED PORTC
#define PIN_LED_GRN _BV(0)
#define PIN_LED_YEL _BV(1)
#elif defined(CONS_SNES)
#define DDR_LED DDRD
#define PORT_LED PORTD
#define PIN_LED_GRN _BV(6)
#define PIN_LED_YEL _BV(7)
#endif

// \\ // \\ // \\ // \\ // \\ // \\ // \\ // \\ // \\ // \\ // \\ // \\ // \\ //

volatile uint8_t event = 0;
uint16_t bat_low_thresh = 0;
uint8_t led_status = 0;

ISR(TIMER1_COMPA_vect) { event = EVENT_TIMER; }
SIGNAL(PCINT2_vect) { event = EVENT_PIN_CHANGE; }
SIGNAL(PCINT1_vect) { event = EVENT_PIN_CHANGE; }
SIGNAL(PCINT0_vect) { event = EVENT_PIN_CHANGE; }

// \\ // \\ // \\ // \\ // \\ // \\ // \\ // \\ // \\ // \\ // \\ // \\ // \\ //

void goToSleep() {
  // Go to sleep until an interrupt wakes us.
  set_sleep_mode(SLEEP_MODE_IDLE);
  sleep_mode();
  // Disable sleep until we're called again.
  sleep_disable();
}

inline void lightLedGreen() {
  PORT_LED |= PIN_LED_GRN;
  PORT_LED &= ~PIN_LED_YEL;
}

inline void lightLedOff() {
  PORT_LED &= ~PIN_LED_GRN;
  PORT_LED &= ~PIN_LED_YEL;
}

inline void lightLedYellow() {
  PORT_LED &= ~PIN_LED_GRN;
  PORT_LED |= PIN_LED_YEL;
}

// \\ // \\ // \\ // \\ // \\ // \\ // \\ // \\ // \\ // \\ // \\ // \\ // \\ //

void loop(void) {
  if (event == EVENT_TIMER) {
    // Blink LED with timer event.
    led_status = !led_status;
  }

  if (event) {
    event = 0;

    power_adc_enable();
    uint16_t batLvl = analogRead(7);
    power_adc_disable();

    // Read the state of all input pins into btnData.
    uint16_t btnData = 0xffff;
    #if defined(CONS_NES)
      if ((PINC & _BV(2)) == 0) btnData &= ~_BV(0x00);  // b
      if ((PINC & _BV(3)) == 0) btnData &= ~_BV(0x02);  // select
      if ((PINC & _BV(4)) == 0) btnData &= ~_BV(0x03);  // start
      if ((PINC & _BV(5)) == 0) btnData &= ~_BV(0x07);  // right
      if ((PIND & _BV(2)) == 0) btnData &= ~_BV(0x06);  // left
      if ((PIND & _BV(3)) == 0) btnData &= ~_BV(0x05);  // down
      if ((PIND & _BV(4)) == 0) btnData &= ~_BV(0x04);  // up
      if ((PIND & _BV(5)) == 0) btnData &= ~_BV(0x08);  // a
    #elif defined(CONS_SNES)
      if ((PINB & _BV(0)) == 0) btnData &= ~_BV(0x01);  // y
      if ((PINB & _BV(6)) == 0) btnData &= ~_BV(0x09);  // x
      if ((PINB & _BV(7)) == 0) btnData &= ~_BV(0x0B);  // rt
      if ((PINC & _BV(0)) == 0) btnData &= ~_BV(0x03);  // start
      if ((PINC & _BV(1)) == 0) btnData &= ~_BV(0x02);  // select
      if ((PINC & _BV(2)) == 0) btnData &= ~_BV(0x07);  // right
      if ((PINC & _BV(3)) == 0) btnData &= ~_BV(0x04);  // up
      if ((PINC & _BV(4)) == 0) btnData &= ~_BV(0x0a);  // lt
      if ((PINC & _BV(5)) == 0) btnData &= ~_BV(0x06);  // left
      if ((PIND & _BV(0)) == 0) btnData &= ~_BV(0x05);  // down
      if ((PIND & _BV(3)) == 0) btnData &= ~_BV(0x00);  // b
      if ((PIND & _BV(4)) == 0) btnData &= ~_BV(0x08);  // a
    #endif

    #ifdef DEBUG
    printf("BATT %04x; DATA %04x; ", batLvl, btnData);
    #endif

    //radio.setChannel(CHANNEL); // To reset PLOS_CNT
    uint8_t ok = radio.write(&btnData, sizeof(btnData));
    #ifdef DEBUG
    printf("%s!\n", ok ? "ok" : "fail");
    #endif

    if (batLvl == 0) {
      // Running from external power.
      if (PIND & _BV(5)) {
        // Not charging: solid green.
        lightLedGreen();
      } else {
        // Charging: solid yellow.
        lightLedYellow();
      }
    } else if (batLvl < bat_low_thresh) {
      // Battery low: Solid yellow status.
      lightLedYellow();
    } else if (led_status) {
      // Battery ok: Flash green/yellow with good/bad link.
      ok ? lightLedGreen() : lightLedYellow();
    } else {
      // Shouldn't happen, but otherwise light off.
      lightLedOff();
    }
  }

  // TODO: Count timer interrupts with no change, enter deep sleep.
  goToSleep();
}
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

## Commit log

2015-01-02 Rough implementation of hardware, and RX software.
    [rx-B_Cu.gbl, rx-B_Mask.gbs, rx-B_SilkS.gbo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]
2015-01-05 v2
    * Schematic revs:
    * TVS protection on TX
    * TX voltage divider moved after the power switch
    * RX adds crystal to run at 16MHz
    RX software tested w/ a real console.
    [rx-B_Cu.gbl, rx-B_Mask.gbs, rx-B_SilkS.gbo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]
2015-01-27 end-to-end working on breadboard
    [rx-B_Cu.gbl, rx-B_Mask.gbs, rx-B_Paste.gbp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]
2015-01-30 finalize TX for SNES
    [rx-B_Cu.gbl, rx-B_Mask.gbs, rx-B_Paste.gbp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]
2015-02-18 finalize software changes to match PCB layout
2015-02-22 a few SNES tweaks, add NES/satellite RX
    [rx-B_Cu.gbl, rx-B_Mask.gbs, rx-B_Paste.gbp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]
2015-02-25 rename kicad files to disambiguate nes from snes
    [rx-nessat-B_Cu.gbl, rx-nessat-B_Mask.gbs, rx-nessat-B_Paste.gbp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]
2015-02-25 manufacturing tweaks
    [rx-nessat-B_Cu.gbl, rx-nessat-B_Mask.gbs, rx-nessat-B_Paste.gbp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]
2015-02-25 routing tweaks
    [rx-nessat-B_Cu.gbl, rx-nessat-B_Mask.gbs, rx-nessat-B_Paste.gbp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]
2015-03-22 Slow program fuses.
    Factory default 1MHz needs to go slower.
2015-03-22 High transmit power, more retries.
2015-03-26 Populate data_nes in the correct order.
    [rxnessat.ino]
2015-03-26 Name latch1; prime data pin correctly.
    [rxnessat.ino]
2015-04-03 NES Sat RX: Interrupts drive data lines.
    Player 1 and 2 only for now.
2015-04-03 Light green LED when battery is charged.
2015-04-03 Do not use atomic blocks.
    To cause a problem, the interrupt has to hit between the two STS
    instructions that would write the two bytes to `gRfData`; the latch ISR
    copies that to `data` to mutate. This is exceedingly unlikely, but the
    atomic block causes enough of a delay to be a real problem, more often.
    [rxsnes.ino]
2015-04-12 Reroute the SNES RX board.
    Both to add a 16MHz crystal and align the holes for easier wiring.
    Refs #2
    [rx-snes-B_Cu.gbl, rx-snes-B_Mask.gbs, rx-snes-B_Paste.gbp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]
2015-04-15 First pass at SNES RX code to match board.
2015-04-17 nes TX as daughter board of original PCB
    [tx-nes-B_Cu.gbl, tx-nes-B_Mask.gbs, tx-nes-B_Paste.gbp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]
2015-05-03 add 16mhz fuse settings
2015-05-03 Fix led pin mixup.
    [rxsnes.ino]
2015-05-03 attach correct interrupt; drive correct data port
    also latch data for transmit, in case of RF activity during the transmit
    window
    [rxsnes.ino]
2015-05-04 Holes big enough to fit standard pins.
    The 16 pin interconnect going to the main board has holes that don't
    really fit a standard 0.1" header pin. They fit, only barely with too
    much force. The new size matches the TX/RX holes, which fit the pin
    comfortably.
    [tx-nes.kicad_pcb, tx-nes.sch]
2015-05-04 Move mounting hole to actual standoff position.
    [tx-nes.kicad_pcb]
2015-05-04 cutout around power jack
    [tx-nes.kicad_pcb]
2015-05-05 updated gerbers
    [tx-nes-B_Cu.gbl, tx-nes-B_Mask.gbs, tx-nes-B_Paste.gbp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]
2015-05-07 Resistor scaled for the WP59GYW bi-color LED.
    [tx-nes.sch]
